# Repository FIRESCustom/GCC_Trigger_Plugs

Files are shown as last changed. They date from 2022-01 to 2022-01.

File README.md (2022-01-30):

FIRESCustom GCC TRIGGER PLUGS:
3D-printable trigger plugs for use in Nintendo GameCube Controllers (GCCs)

GCCs have two sensors per trigger: one analog slider and one digital button:  
- SHORT: Short analog pull followed by a digital "click." Reduces the overall stroke length of the trigger, but preserves both analog and digital inputs (i.e. Melee lightshielding)
- LONG: Immediate digital "click." Used when digital input only is desired.

PRINTING NOTES:  
- Due to variances between 3D printers and trigger shafts, X/Y scaling MUST be adjusted to get a good fit!  
- Plugs should be printed with the flat circular face on the bed of the printer.
- Layer seam can be placed along any of the three recesses, preventing layer blobs / voids from affecting the fit.  
- Due to variances between OEM triggers, the same plug will fit loosely in some triggers and very tightly in others - this is normal.  
- If a tight fit is desired, printing with PETG is recommended over PLA. PETG's added toughness will help prevent the plug stem from snapping off inside the trigger if it gets stuck.

FIRES CUSTOM CONTROLLER  
www.firescc.com  
REVISION: v7 
DATE: 2021-Jan-29

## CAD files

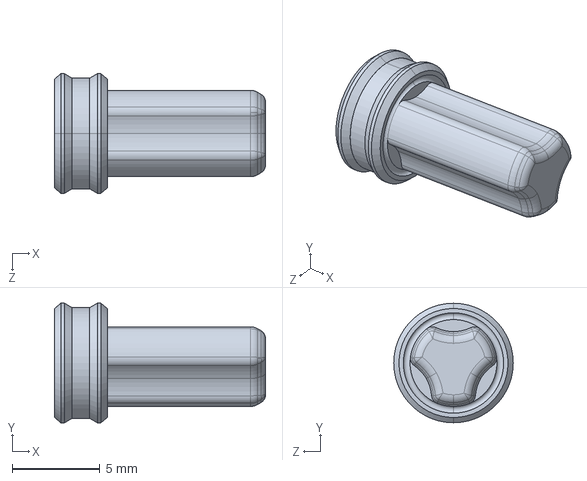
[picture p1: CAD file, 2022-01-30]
FIRES SHORT Trigger Plugs v7.STEP
12.0 x 6.80 x 6.80 mm

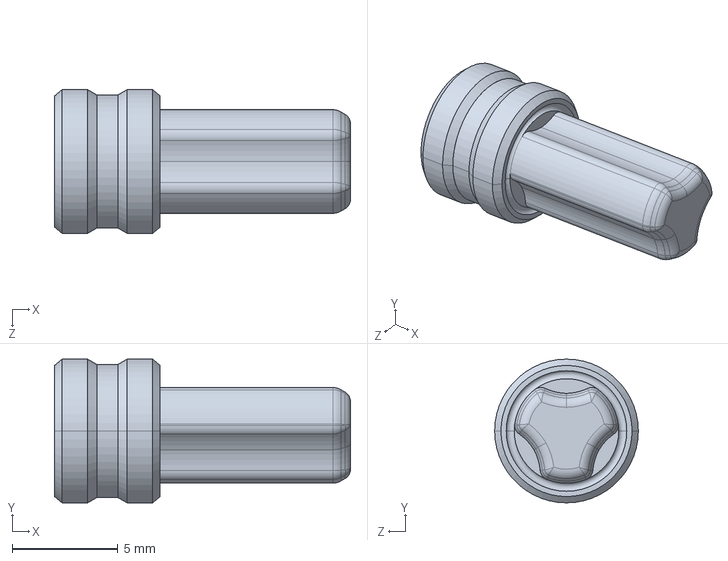
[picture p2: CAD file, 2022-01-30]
FIRES LONG Trigger Plugs v7.STEP
14.0 x 6.80 x 6.80 mm
